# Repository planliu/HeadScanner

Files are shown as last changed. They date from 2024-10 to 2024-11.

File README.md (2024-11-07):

# HeadScanner
3D Head Scanner powered by Polycam and iPhone LiDAR technology, designed and built with a custom mechanical setup using two NEMA 23 stepper motors for precise rotation and panning. The project showcases skills in mechanical design, SolidWorks modeling, and additive manufacturing for face scanning applications.  
Demonstration video can be found [here](https://youtu.be/GNz_M5EVXv4)

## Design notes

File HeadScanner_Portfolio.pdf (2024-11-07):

# 3D Head Scanner Powered by Polycam

## Project Portfolio

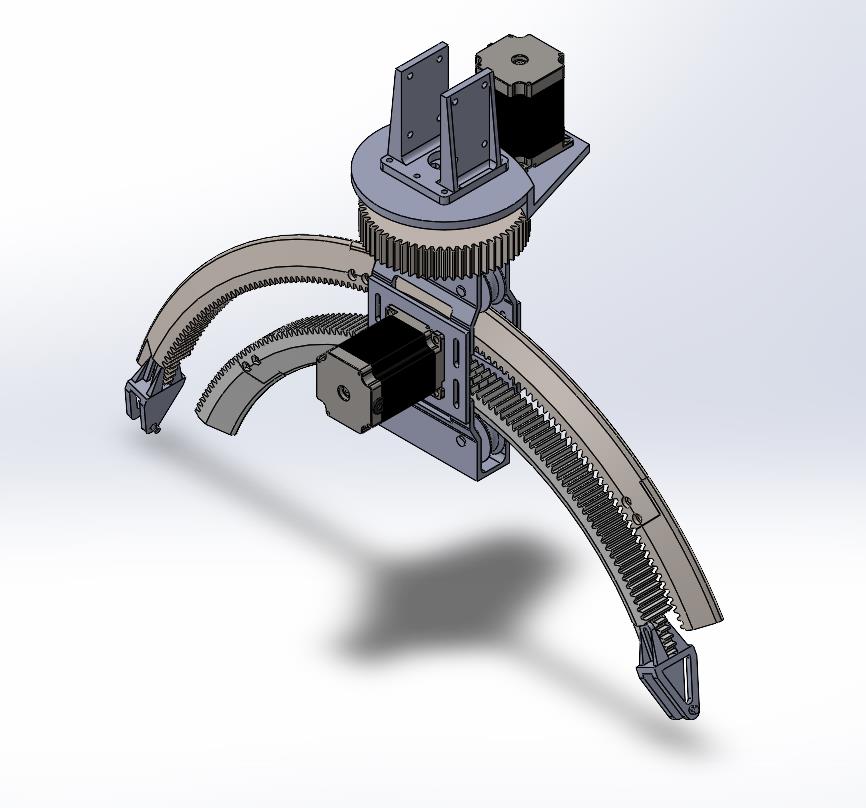
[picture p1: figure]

Park Lan-Liu
Mechanical Engineering Student at Queen’s University

Soft skills:
Mechanical design, Additive Manufacturing knowledge, General Dimensioning and Tolerances, Design for Assembly, Collaboration
Technologies:
SolidWorks, Bambu Slicer software

My personal passion project, the 3D Head Scanner, aims to accurately digitize faces. This device captures intricate details of human features, enabling a high level of precision that could be used for various applications. One significant area is the creation of customized prosthetics, where detailed scans can lead to the ability to more accurately recreate a person’s facial features, and to better-fitting devices tailored to the unique contours of an individual's face. Additionally, the scanner could facilitate the development of personalized digital avatars for use in virtual environments, and the opportunity to digitize memories with more depth and dimensionality of a person's features than traditional photography. The device utilizes the iPhone’s Lidar scanner in conjunction with the Polycam app to capture accurate 3D scans of human heads. This project involved designing a custom mechanical setup that uses a system of two NEMA 23 stepper motors to control the rotation in the vertical axis, and circular panning motion. The integration of various components, such as stepper motors for smooth movement and a sturdy frame for stability, showcases my hands-on skills in mechanical design and engineering. Through this project, I explored additive manufacturing, using 3D printing to create the scanner's components. The result not only enhances my understanding of 3D modeling and scanning technologies but also exemplifies my commitment to innovation in mechanical design. This head scanner serves as a testament to my ability to bring concepts to life, bridging the gap between theoretical knowledge and practical application.

## Lower Panning Assembly

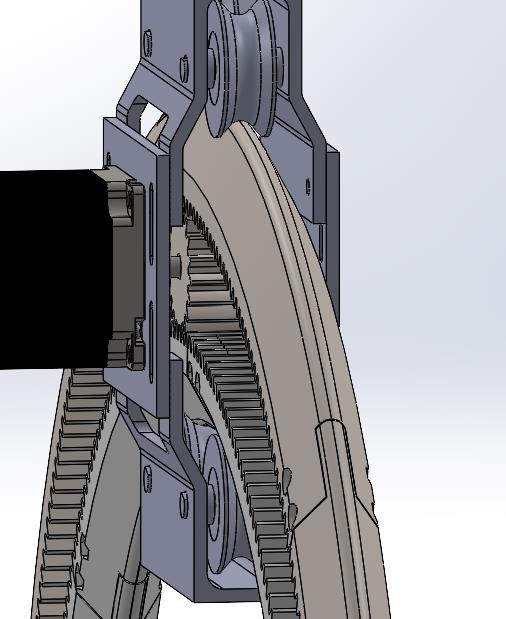
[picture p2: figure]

Figure 1 Side view showcasing the gearing mechanism driven by the lower stepper motor, responsible for precise panning motion control in the 3D Head Scanner.
The head scanner features two mechanical systems. The lower stepper motor controls the circular panning movement of the two arms, which move in opposition on opposite sides of the driving gear. The arms move along a pair of bearing rollers, supporting under and above the lower and upper arms respectively.
The assembly was designed with a double-arm system to include a counterweight that moves in opposition to the phone, maintaining balance and allowing smoother movement of the upper assembly.

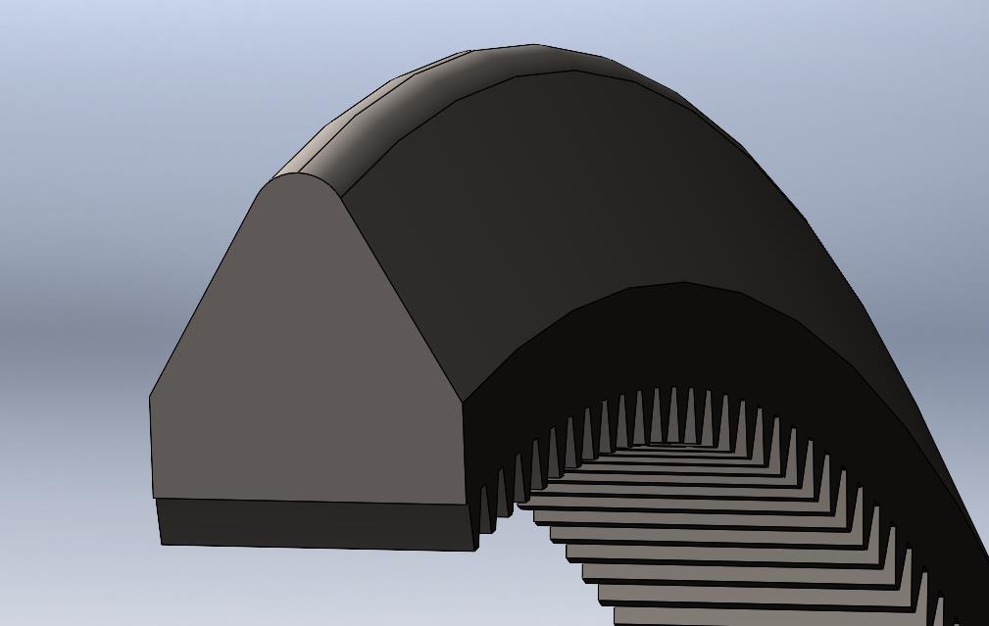
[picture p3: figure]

Figure 2 Triangular side profile of the arms, designed to prevent lateral flexing and wobble, enabling smooth operation without the need for additional support rollers.
I designed the side profile of the arms in a triangular shape, eliminating the need for additional rollers to support the lateral movement. This prevents unwanted flexing or wobbling during operation and simplifies the overall assembly by minimizing the number of components required.

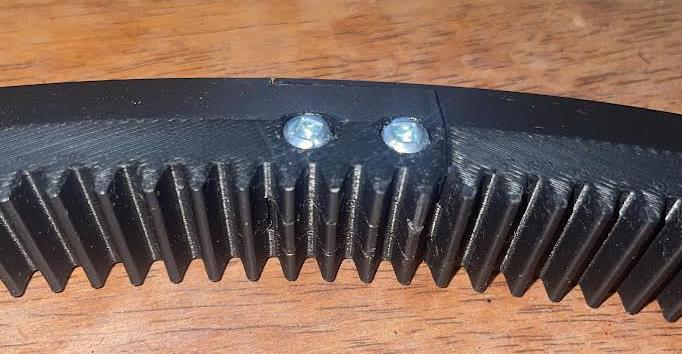
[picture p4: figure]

Figure 3 Close-up view of the arms. Restricted by the bed size of the 3d Printer, each arm is made in segments and held together by m4 nuts and bolts with recessed holes for each. This demonstrates precise tolerances in the assembly that ensure a solid and stable connection.

## Upper Rotational Assembly

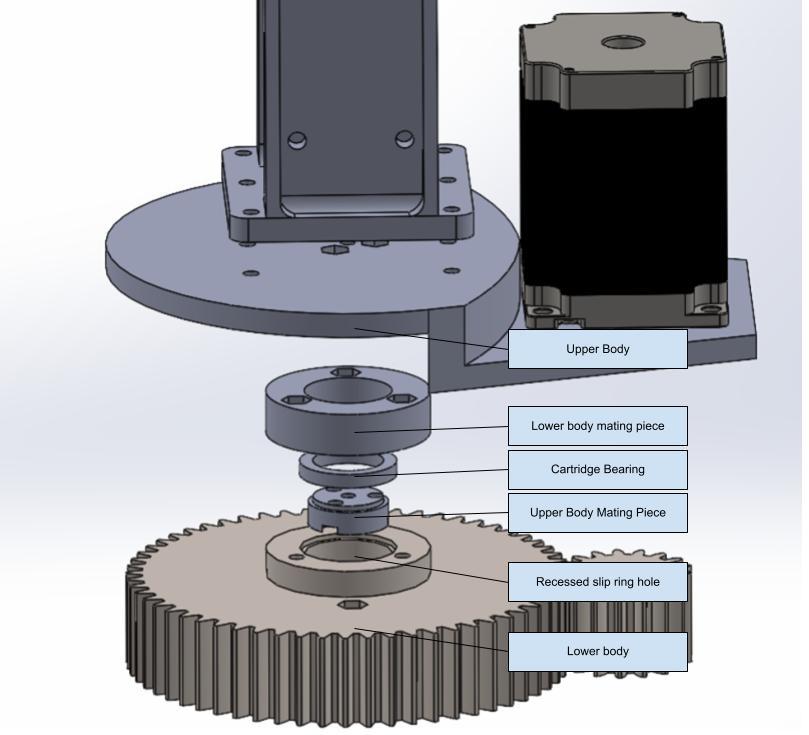
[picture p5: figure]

Figure 4 Exploded view of the assembly, illustrating the integration of the cartridge bearing that facilitates rotation of the lower body, along with designated space for the slip ring to enable smooth electrical connections during movement.
The rotation of the lower panning assembly is supported by a 20x27x4mm cartridge bearing. The upper body is secured to the inner bearing race through a mating piece with a bearing retaining circular cutout, with the same dimensions as the cutout on the upper body. The lower body is designed with a recessed cutout to accommodate the outer bearing race, and another mating piece that mirrors this cutout for precise alignment.

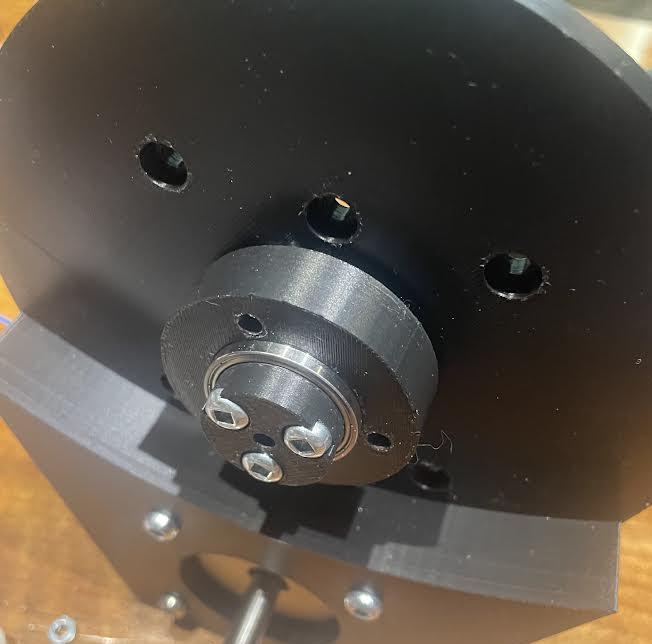
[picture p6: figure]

Figure 5 Image of the cartridge bearing mounted into the upper body via the upper body mating piece, with the outer race of the bearing securely recessed into the lower body mating piece
The retainer for the upper assembly includes a cable passthrough for wires from the slip ring, which is mounted into a recessed hole in the lower body. The slip ring enables control of the lower stepper motor while allowing electrical signals and power to pass through the rotating joint without twisting the wires, which would otherwise limit the range of motion.

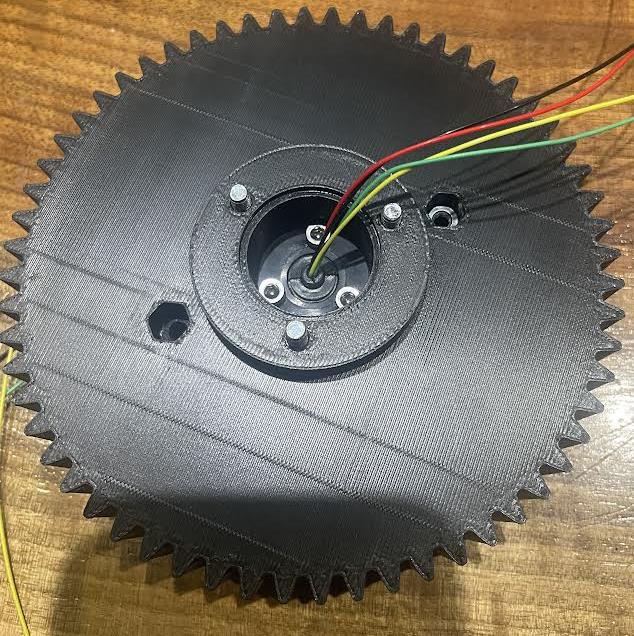
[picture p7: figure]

Figure 6 Image of the slip ring securely mounted into the recessed slip ring hole of the lower body, using m3 bolts

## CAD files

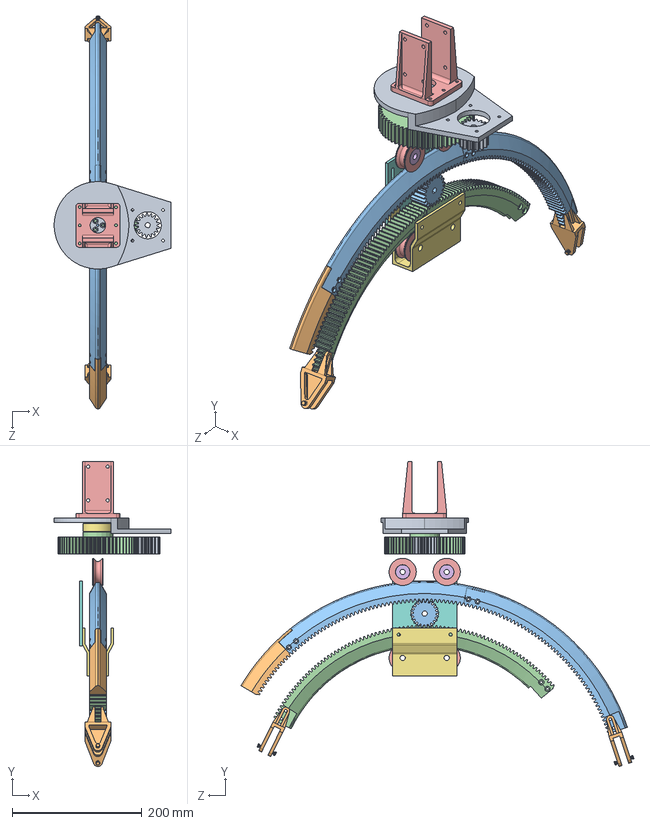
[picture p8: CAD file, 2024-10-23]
Solidworks_Files/SCANNER.SLDASM
180.1 x 471.0 x 606.7 mm
SCANNER_bodymidL
SCANNER_bodybottom
skateboard bearing x 9
SCANNER_wheel x 4
SCANNER_innerarm x 2
SCANNER_lowergearsmall
SCANNER_phonemount x 2
SCANNER_upperbody
SCANNER_upperbodymating
SCANNER_uppergearlargemating
SCANNER_largebearing
SCANNER_woodmount
SCANNER_uppergearlarge
SCANNER_outerarm1 x 2
SCANNER_outerarm_end
scanner_uppergearsmall

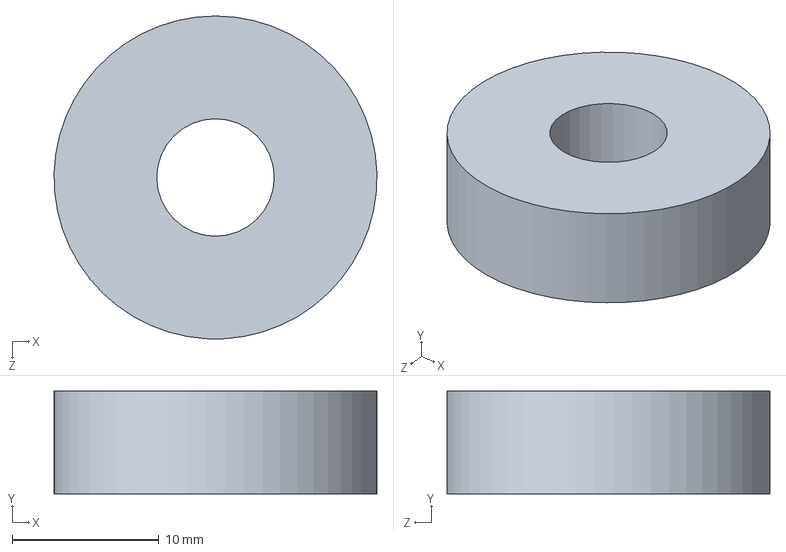
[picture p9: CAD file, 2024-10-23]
Solidworks_Files/skateboard bearing.SLDPRT
22.0 x 7.00 x 22.0 mm

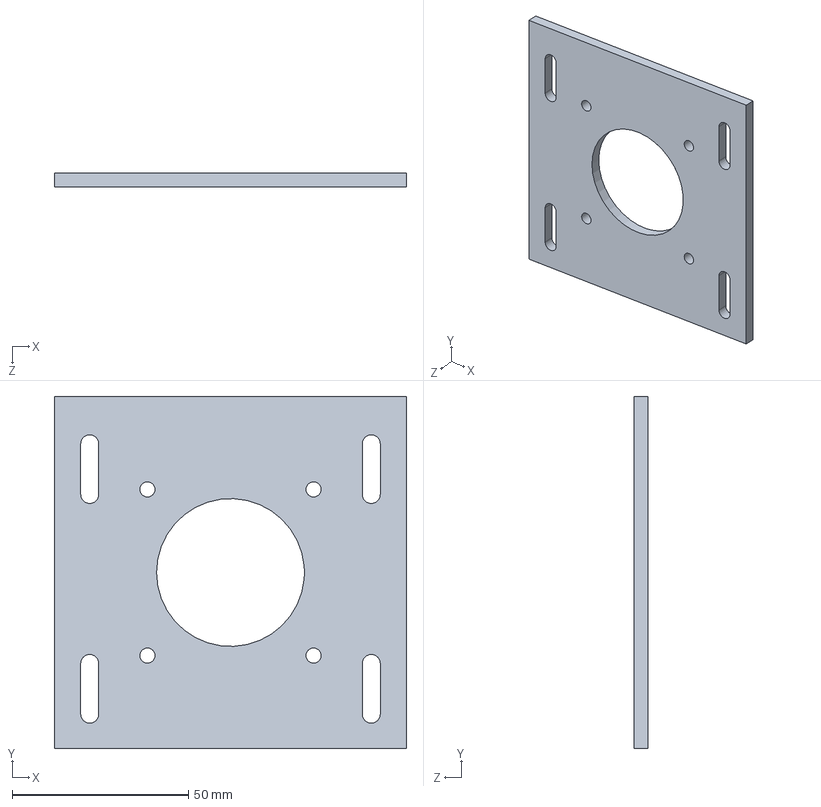
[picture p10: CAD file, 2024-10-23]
Solidworks_Files/SCANNER_bodymidL.SLDPRT
100.0 x 100.0 x 4.00 mm

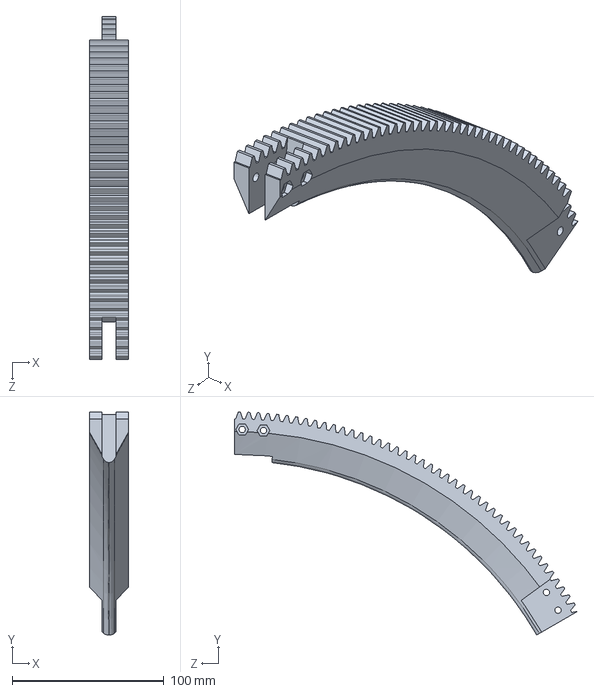
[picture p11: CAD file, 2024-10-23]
Solidworks_Files/SCANNER_innerarm.SLDPRT
26.0 x 147.0 x 226.1 mm

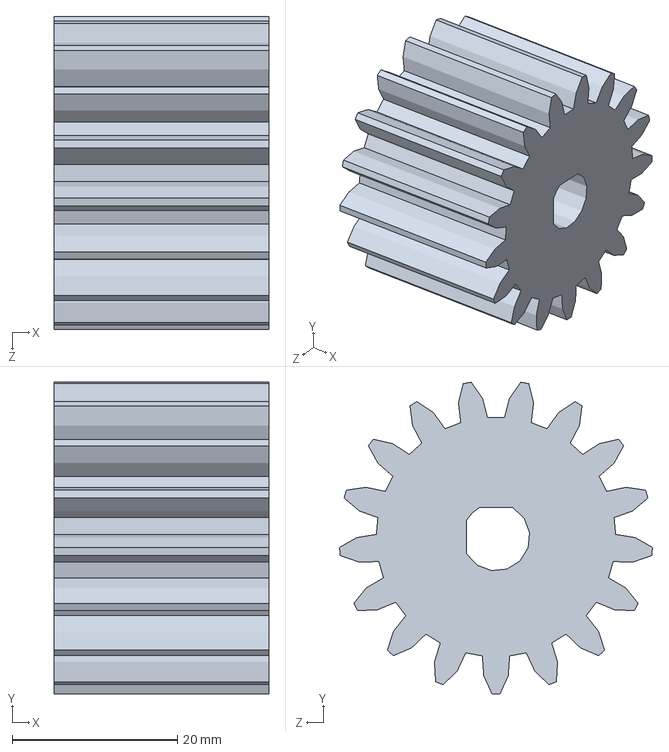
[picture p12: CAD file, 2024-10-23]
Solidworks_Files/scanner_uppergearsmall.SLDPRT
26.0 x 37.8 x 37.9 mm

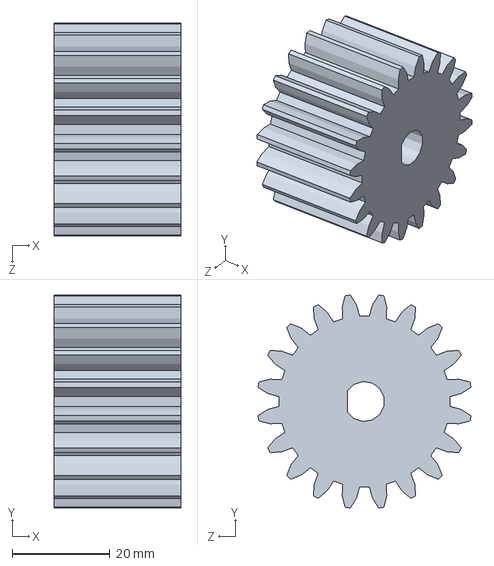
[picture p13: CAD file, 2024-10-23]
Solidworks_Files/SCANNER_lowergearsmall.SLDPRT
26.0 x 43.6 x 43.6 mm

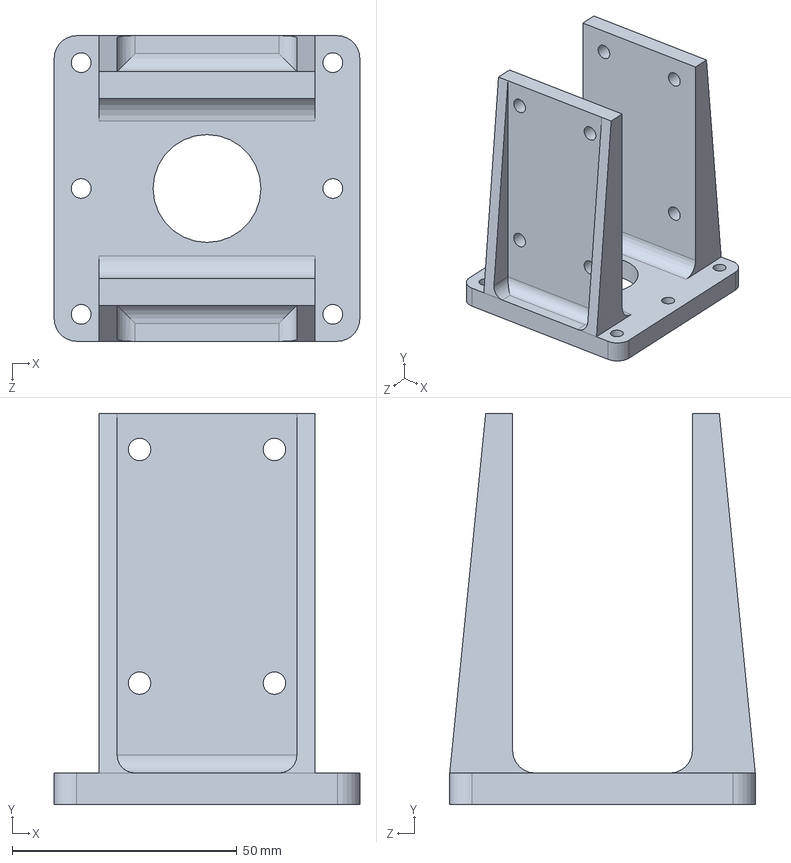
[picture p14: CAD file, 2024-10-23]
Solidworks_Files/SCANNER_woodmount.SLDPRT
68.0 x 87.0 x 68.0 mm

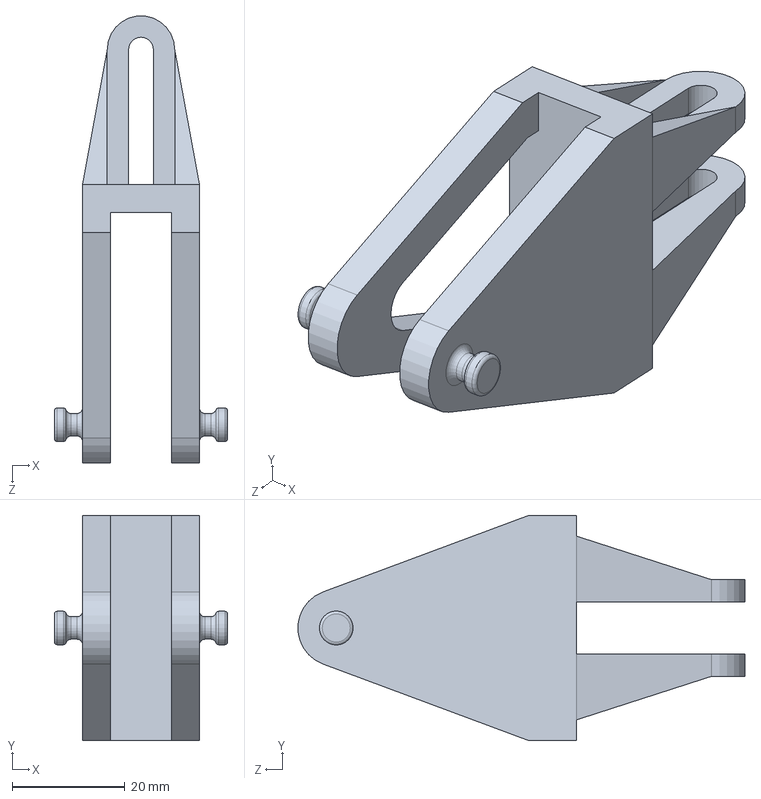
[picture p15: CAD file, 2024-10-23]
Solidworks_Files/SCANNER_phonemount.SLDPRT
30.8 x 40.0 x 79.4 mm

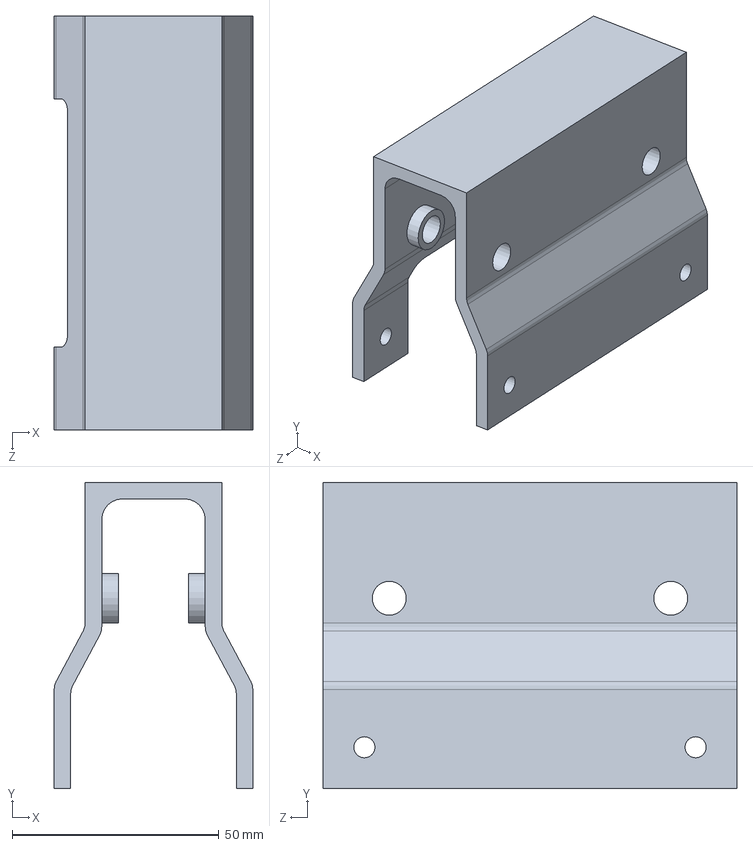
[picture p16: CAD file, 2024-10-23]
Solidworks_Files/SCANNER_bodybottom.SLDPRT
48.0 x 74.0 x 100.0 mm

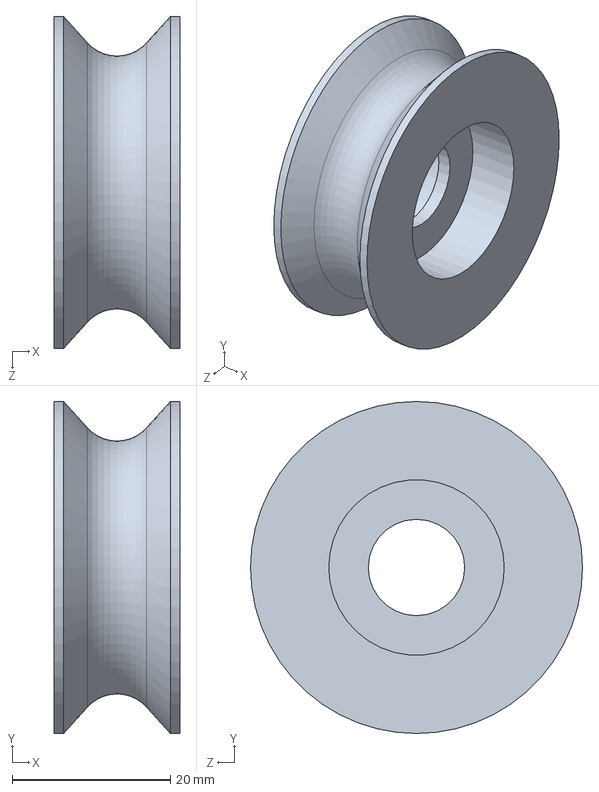
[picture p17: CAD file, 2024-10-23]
Solidworks_Files/SCANNER_wheel.SLDPRT
15.9 x 42.0 x 42.0 mm

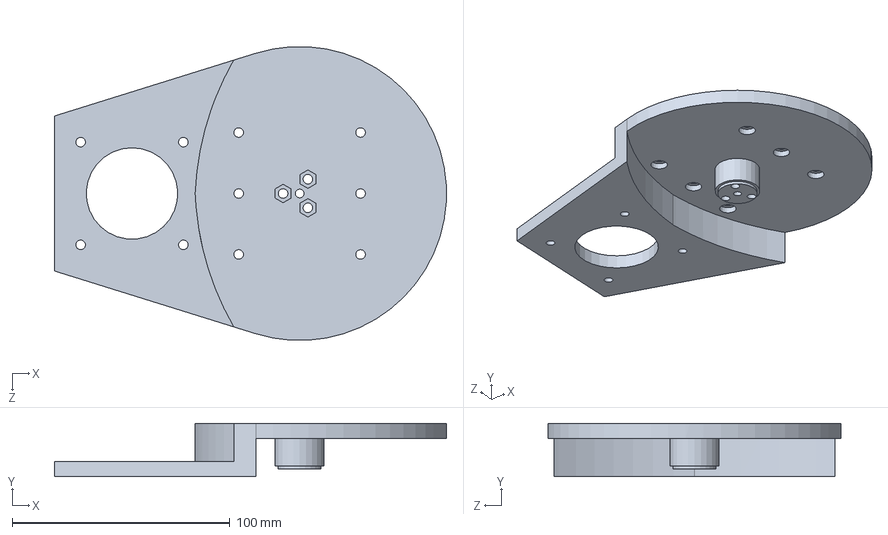
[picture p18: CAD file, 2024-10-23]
Solidworks_Files/SCANNER_upperbody.SLDPRT
180.1 x 24.5 x 134.8 mm

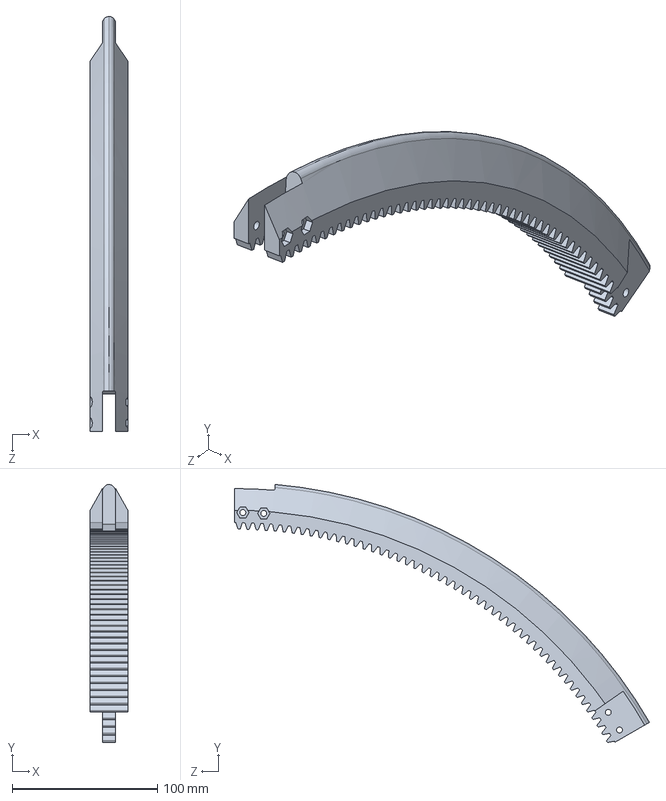
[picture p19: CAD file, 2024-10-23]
Solidworks_Files/SCANNER_outerarm1.SLDPRT
26.0 x 177.7 x 285.8 mm

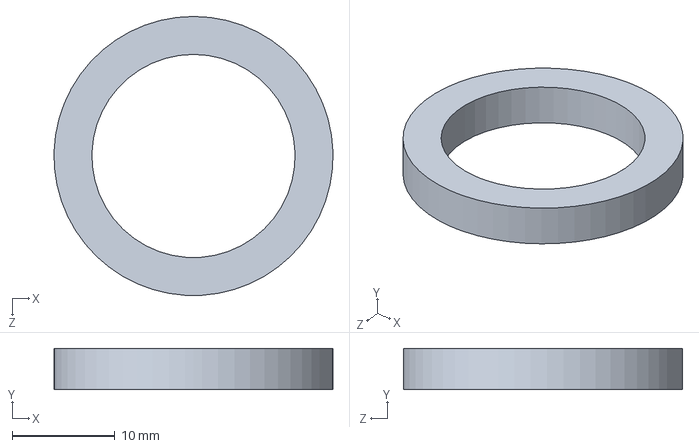
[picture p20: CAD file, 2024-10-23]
Solidworks_Files/SCANNER_largebearing.SLDPRT
27.2 x 4.00 x 27.2 mm

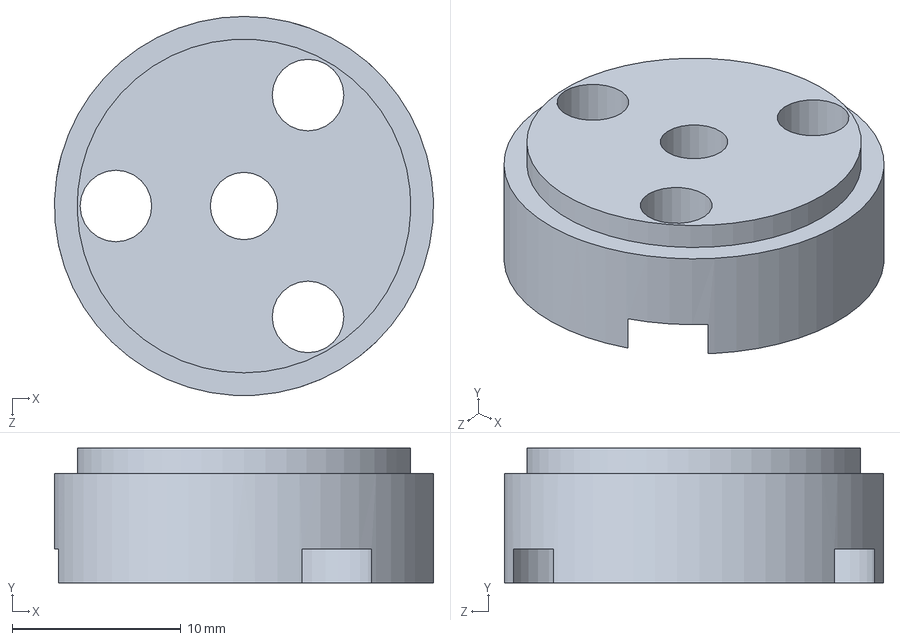
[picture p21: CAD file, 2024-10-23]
Solidworks_Files/SCANNER_upperbodymating.SLDPRT
22.5 x 8.00 x 22.5 mm

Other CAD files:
Solidworks_Files/SCANNER_middlegear.SLDPRT
Solidworks_Files/SCANNER_outerarm_end.SLDPRT
Solidworks_Files/SCANNER_uppergearlarge.SLDPRT
Solidworks_Files/SCANNER_uppergearlargemating.SLDPRT
Solidworks_Files/SCANNER_bodymidR.SLDPRT
Solidworks_Files/SCANNER_bodymidR2.SLDPRT
Solidworks_Files/SCANNER_bodytop.SLDPRT
Solidworks_Files/SCANNER_innerarm_end.SLDPRT
Solidworks_Files/SCANNER_shaft.SLDPRT
